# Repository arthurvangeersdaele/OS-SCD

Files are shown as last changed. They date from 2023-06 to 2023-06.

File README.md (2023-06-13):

# The open-source Sequential Compression Device

## Description
The enhancement of an OS Sequential Compression Device (SCD), which combines software and hardware components, to create a suitable hospital device involves a meticulous and iterative process. The objective is to optimize its functionality, usability, and effectiveness, ensuring it meets the specific needs of healthcare professionals and patients alike.

This project has been initied by Schara et al. from Rice University, Huston, and was taken up for a master thesis at UCLouvain by Arthur Van Geersdaele and Thalie Sarafidis. 

## Structure of the .git
A directory has been created for every aspect of the prototype:
- The eletronic design
- The Arduino SCT Software
- The pneumatic band conception
- The risk management (empty at the time this txt file is written)

Don't hesitate to create a new branch for every new iteration of the prototype.

## Support
Arthur Van Geersdaele permanent email: arthurvg@gmail.com

## Acknowledgment
First and foremost, we would like to thank our supervisors, David Bol and Benoît Herman,
for their guidance and support during this academic year. Without their assistance and
suggestions this work would not have been the same. Thank you for all the feed-backs,
your ideas and critiques always helped us to progress.

This thesis could not have existed without the financing by the donations made during
a fundraiser launched by the Louvain Foundation in the first months of the Covid-19
pandemic for the development and distribution of open-source medical devices. We want
to thank the Louvain Fondation and its generous donors. Their donations allowed us to
work on a exciting project with meaning in our eyes. We hope they will be proud of the
work we accomplished.

Any opinions, findings, and conclusions or recommendations expressed in this material are those of the author(s) and do not necessarily reflect the views of the Louvain Fundation.

## License
This project is published under a Creative Commons CC-BY licence by Mark Schara, Mingde Zeng, Jumet and Daniel J. Preston in 2022.

## Overview

<img src="https://lh3.googleusercontent.com/uw4Hd-o32ru7BUOAbB3s1_LTyGWp65Da7H4i2JahnDTs6Ar5mRC0plo9FD7Agp0bvpjEJgBAzZyAgz1ODGIi2wvJs8SYI_CQhsvGnffs6thqfykDg9P1XCusFHrppcjr6rP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" alt="Image of the OS-SCD device interface" width="400"/>

<img src="https://lh3.googleusercontent.com/Dr_NfxmwPY0K1YTv_ehdX9OtSePjZ78id5i1sB04MkSCgEVkiPq_8iiFihfI5J00OjZHkZ0deeg7UaLteDr7LWMCece_ab0Vw5Il7_U0E2uyAFjOePnH3NXgfk2ZkVE7Rpe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" alt="Image of the 3 bands wrapped around the user leg" width="400"/>

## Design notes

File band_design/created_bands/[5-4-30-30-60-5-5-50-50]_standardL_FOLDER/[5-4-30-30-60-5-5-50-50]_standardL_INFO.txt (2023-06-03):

WARNING: SVG has to be converted to paths before being converted to RXF for laser-cutting.
         For better cutting, you can combine the curves using the cutting program.
Tips: The ID of the band is structured as follow 
      [n - ID - l - g - L - ll - gg - Gplus - Gminus]_tag
=========================================================================================

Design specifications
- Reference ID: [5-4-30-30-60-5-5-50-50]_standardL
- Input diameter: 4mm
- Number of pouches: 5
- Dimensions of a pouch: 30x30mm
- Dimensions of the band: 320.0x60mm
- Distance between each pouch: 5mm
- Inner tube width: 5mm
- Additionnal length at the beginning of the pouch-chain (air input to the left): 50mm
- Additionnal length at the end of the pouch-chain: 50mm
- Elbow dimensions: 20x50mm
Others
- TPU Textile dimensions needed for the 2 heat_sealable_layers: 320.0x125mm
- Baking paper dimensions needed for the intermediate_layer: 190x72.5mm
- Nyamara Volume of the band: 31746.77420681033mm3
- Nyamara Volume of the band considering interconnections: 31864.35485202074mm3

NB: The id-box dimensions needed for laser-cutting are written at the end of the filenames.
NB2: Depending on the material used, it can be a retractation of the fabric during the laser-cutting.
     Take that in account while setting your parameters.

Additionnal information on the fabrication process, handwritten
- Material: One-sided TPU coated Textile (70d)
- Fusion process parameters: T=200Celsius, t=30s (set to 200C, 30s default for TPU)

Other notes, remarks..., about [5-4-30-30-60-5-5-50-50]_standardL
***************************************************************************************

***************************************************************************************

 Info file automatically generated at date : 23/04/27 - time : 16h03min40s  using IPCdevice_designer_v2.py

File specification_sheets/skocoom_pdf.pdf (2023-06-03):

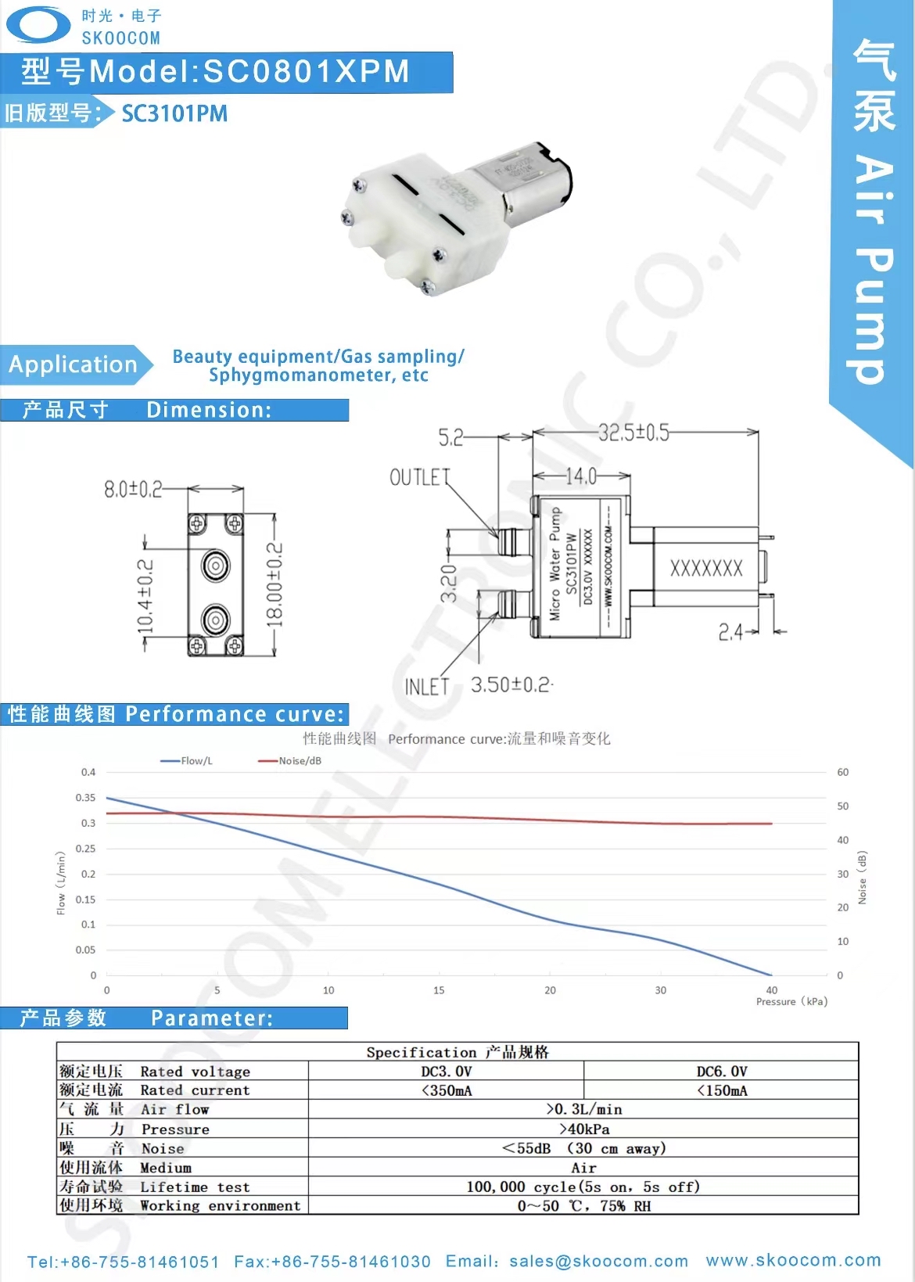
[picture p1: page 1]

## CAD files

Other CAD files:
band_design/created_bands/[5-4-30-30-60-5-5-50-50]_standardL_FOLDER/[5-4-30-30-60-5-5-50-50]_standardL_intermediate_layer(190x72.5mm).dxf
band_design/created_bands/[5-4-30-30-60-5-5-50-50]_standardL_FOLDER/[5-4-30-30-60-5-5-50-50]_standardL_global_render.dxf

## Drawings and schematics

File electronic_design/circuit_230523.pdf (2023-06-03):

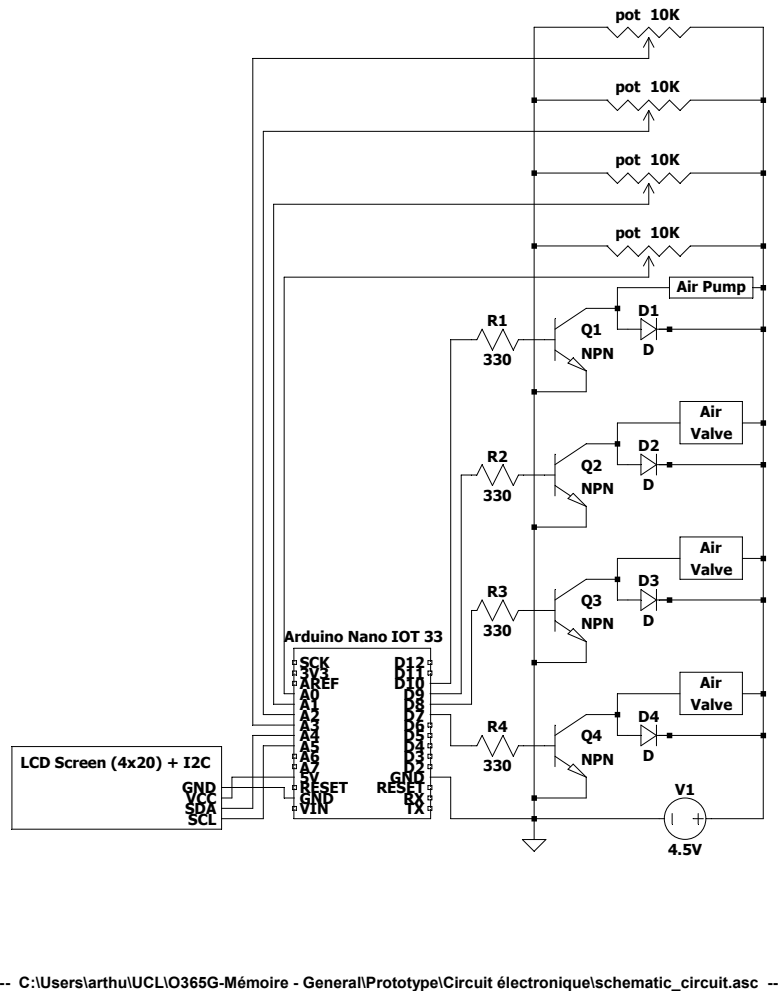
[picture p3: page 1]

Arduino Nano IOT 33
SCK 3V3 AREF A0A1A2A3A4A5A6A75VRESET GND VIN

GND VCC SDA SCL

--- C:\Users\arthu\UCL\O365G-Mémoire - General\Prototype\Circuit électronique\schematic_circuit.asc ---

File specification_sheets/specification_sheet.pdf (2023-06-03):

OS SCD prototype – Overview sheet of the components | may the 30th 2023
p. 1 / 5

## Components - precise description

Drive links may be deprecated or not up-to-date, please refer to the Forge
GitLab linked to this project

The susmentionned GitLab contains every details of the project.

All the specifications sheets we found are stored here https://drive.google.com/drive/folders/1-vRpSUxZW-rc5TYF7eE5loehlPPyNJy3?usp=sharing

Here are some useful links to find electromechanical components :
- https://www.digikey.be/fr/
- RS | Distributeur de composants électroniques et solutions industrielles (rs-online.com)
- https://www.mouser.fr/

The following elements are enhanced descriptions of the components used to build the OS-SCD prototype. With added mechanical and electronical specifications.

Microcontroller
Complete name | Arduino Nano IOT 33with headers (SKU: ABX00032)
Dimensions | 48mm x 18mm
Weight | 5 grams
Operating voltage | 3.3V
Connections | Two 15-pin connectors (one on each side)
Comment | The integrated DC-DC power supply allows you to power the board up to 21V while maintaining high efficiency and providing a significant amount of current to external devices without overheating. 1 piece for 1 device.
Where to buy it | https://store.arduino.cc/products/arduino-nano-33-iot-with-headers
Price | 23.40€/pc.

Battery (from the initial prototype, not implemented in the device yet)
Complete name | Galaxy 2S (7.4V) 120 mAh Lipoly Battery Pack
Dimension s | 19 x 25 x 15.5mm
Weight | 11 grams
Tension de sortie | 7.4V
Connexion s | Mating connector : JST

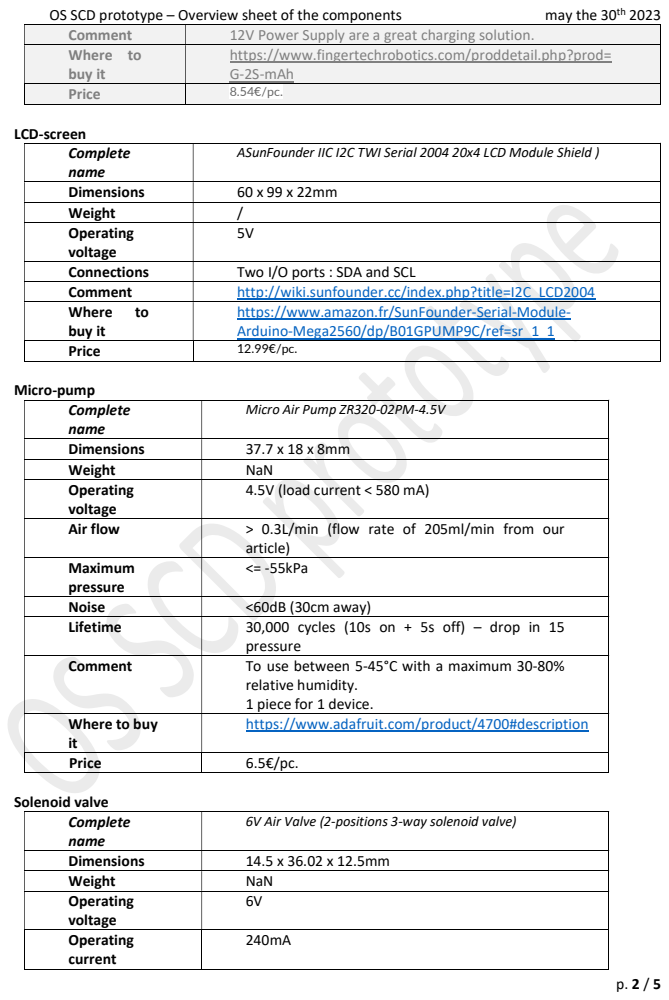
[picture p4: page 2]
LCD-screen; Micro-pump; Solenoid valve

Comment | 12V Power Supply are a great charging solution.
Where to buy it | https://www.fingertechrobotics.com/proddetail.php?prod=G-2S-mAh

Price | 8.54€/pc.

Complete name | ASunFounder IIC I2C TWI Serial 2004 20x4 LCD Module Shield )

Dimensions | 60 x 99 x 22mm
Weight | /
Operating voltage | 5V

Connections | Two I/O ports : SDA and SCL
Comment | http://wiki.sunfounder.cc/index.php?title=I2C_LCD2004
Where to buy it | https://www.amazon.fr/SunFounder-Serial-Module-Arduino-Mega2560/dp/B01GPUMP9C/ref=sr_1_1

Price | 12.99€/pc.

Complete name | Micro Air Pump ZR320-02PM-4.5V

Dimensions | 37.7 x 18 x 8mm
Weight | NaN
Operating voltage | 4.5V (load current < 580 mA)

Air flow | > 0.3L/min (flow rate of 205ml/min from our article)

Maximum pressure | <= -55kPa

Noise | <60dB (30cm away)
Lifetime | 30,000 cycles (10s on + 5s off) – drop in 15 pressure

Comment | To use between 5-45°C with a maximum 30-80% relative humidity. 1 piece for 1 device.

Where to buy it | https://www.adafruit.com/product/4700#description

Price | 6.5€/pc.

Complete name | 6V Air Valve (2-positions 3-way solenoid valve)

Dimensions | 14.5 x 36.02 x 12.5mm
Operating voltage | 6V

Operating current | 240mA

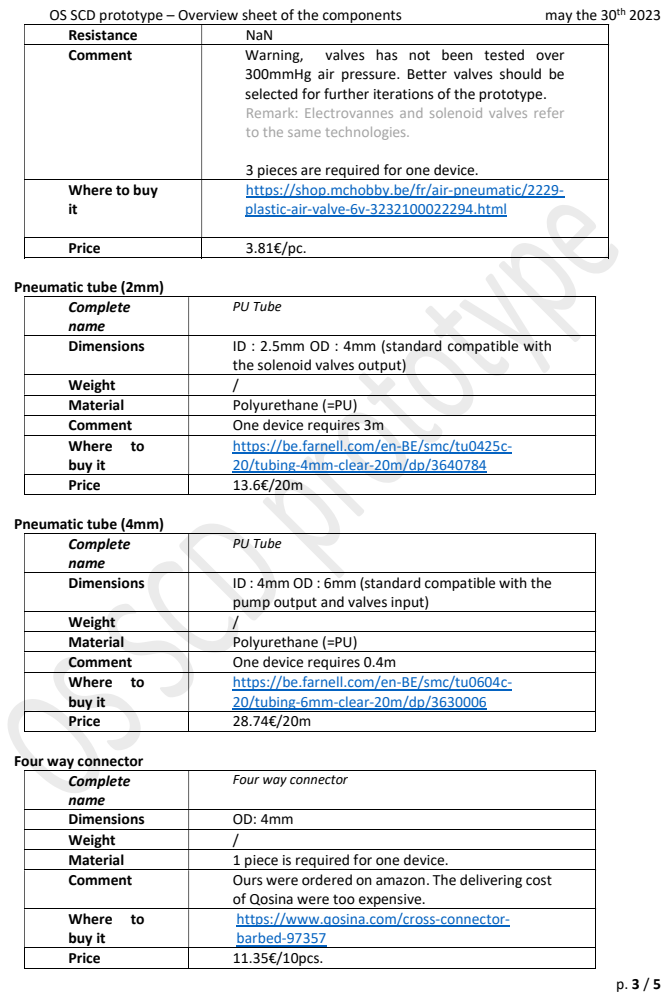
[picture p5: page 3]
Pneumatic tube (2mm); Pneumatic tube (4mm)

Resistance | NaN
Comment | Warning, valves has not been tested over 300mmHg air pressure. Better valves should be selected for further iterations of the prototype. Remark: Electrovannes and solenoid valves refer to the same technologies. 3 pieces are required for one device.

Where to buy it | https://shop.mchobby.be/fr/air-pneumatic/2229-plastic-air-valve-6v-3232100022294.html

Price | 3.81€/pc.

Complete name | PU Tube

Dimensions | ID : 2.5mm OD : 4mm (standard compatible with the solenoid valves output)

Weight | /
Material | Polyurethane (=PU)
Comment | One device requires 3m
Where to buy it | https://be.farnell.com/en-BE/smc/tu0425c-20/tubing-4mm-clear-20m/dp/3640784

Price | 13.6€/20m

Dimensions | ID : 4mm OD : 6mm (standard compatible with the pump output and valves input)

Comment | One device requires 0.4m
Where to buy it | https://be.farnell.com/en-BE/smc/tu0604c-20/tubing-6mm-clear-20m/dp/3630006

Price | 28.74€/20m

Four way connector

Complete name | Four way connector

Dimensions | OD: 4mm
Material | 1 piece is required for one device.
Comment | Ours were ordered on amazon. The delivering cost of Qosina were too expensive.

Where to buy it | https://www.qosina.com/cross-connector-barbed-97357

Price | 11.35€/10pcs.

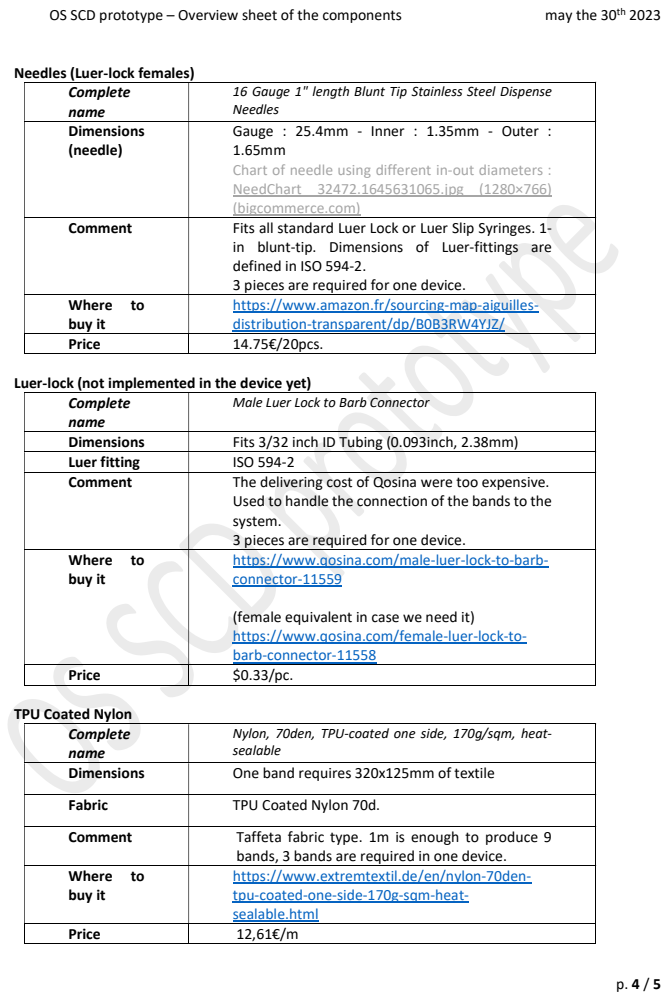
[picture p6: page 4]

Needles (Luer-lock females)

Complete name | 16 Gauge 1" length Blunt Tip Stainless Steel Dispense Needles

Dimensions (needle) | Gauge : 25.4mm - Inner : 1.35mm - Outer : 1.65mm Chart of needle using different in-out diameters : NeedChart__32472.1645631065.jpg (1280×766) (bigcommerce.com)
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

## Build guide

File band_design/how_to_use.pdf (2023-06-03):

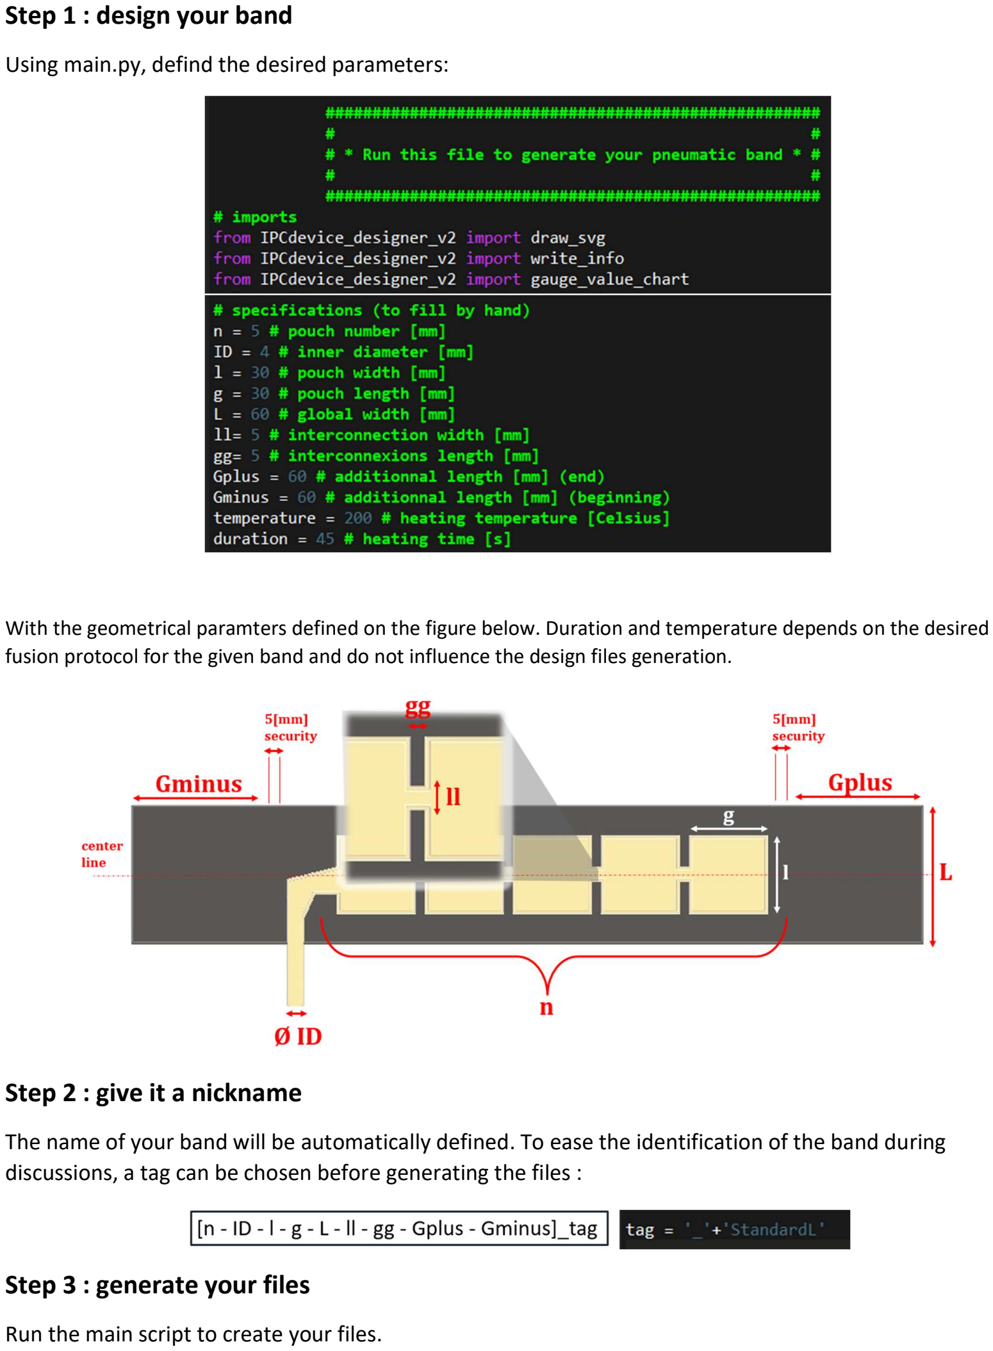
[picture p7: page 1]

Step 1 : design your band

Using main.py, defind the desired parameters:

With the geometrical paramters defined on the figure below. Duration and temperature depends on the desired fusion protocol for the given band and do not influence the design files generation.

Step 2 : give it a nickname

The name of your band will be automatically defined. To ease the identification of the band during discussions, a tag can be chosen before generating the files :

Step 3 : generate your files

Run the main script to create your files.

Step 4 : find your files

After the run, a folder with the name of your band +”_FOLDER” is automatically created in the same repertory as the main.py script.

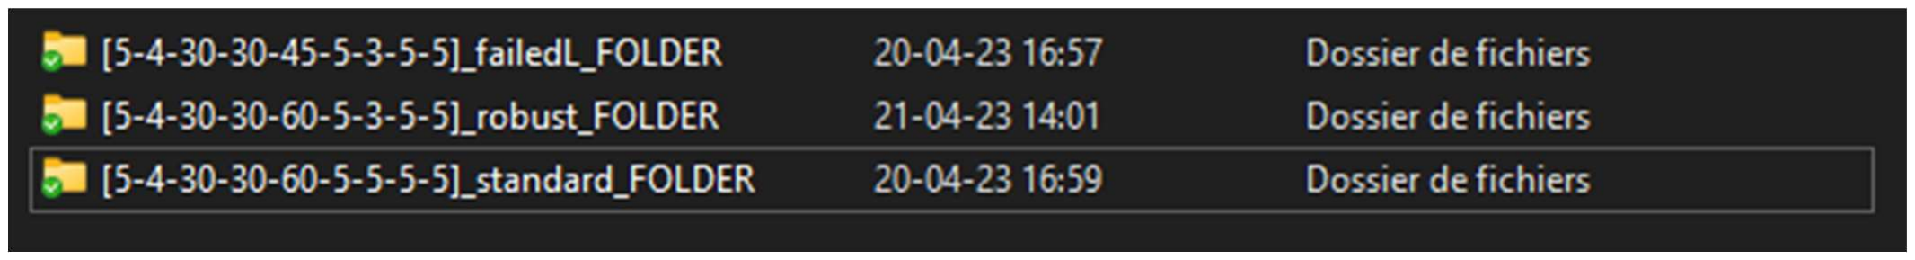
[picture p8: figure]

In the folder, all the needed files are labeled by the name of the band in case they need to be exported out of their initial folder.

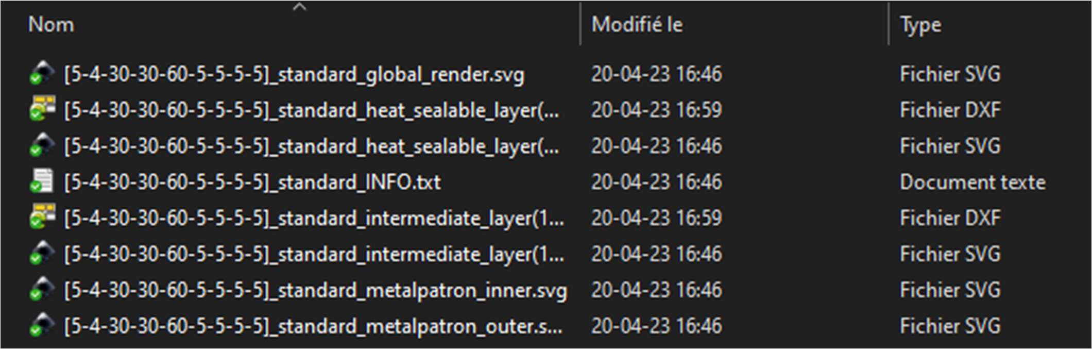
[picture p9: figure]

Among the different files, you will find :
A global render of the band
To verify that the design is correct at first sight. The file is of .svg format.

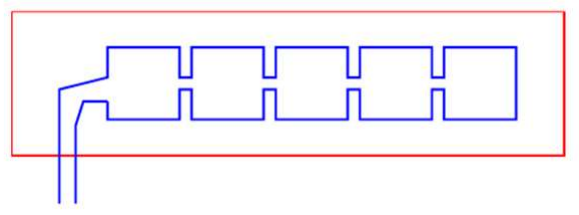
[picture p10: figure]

The distinct cutting files for the heat-sealable layers and the intermediate layer
WARNING: You will need to convert the .svg files to .RXF in order to use them with a laser-cutter.

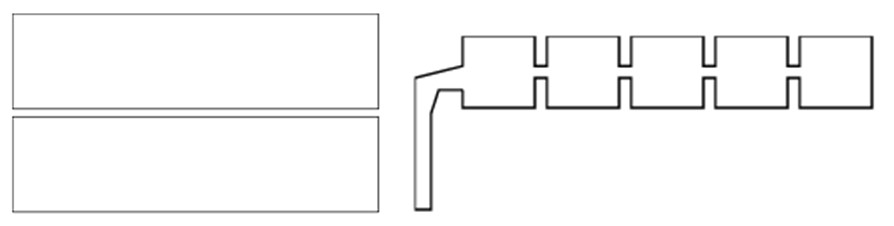
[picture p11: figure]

A first design of a metal-stamp: metal_patron files
They were never tested, but they aim to create a metal stamp to remove the ned of a non-stick layer inside the band.

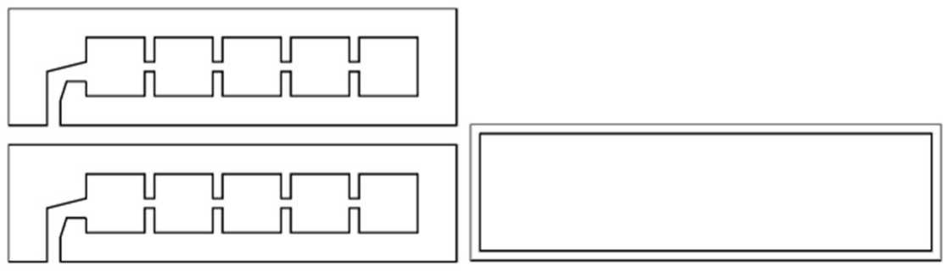
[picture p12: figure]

An info file that resume all the information about the band
The INFO.txt file is the key of the band identification system. It contains everything that is needed to accelerate the fabrication process and to use the band for testing.

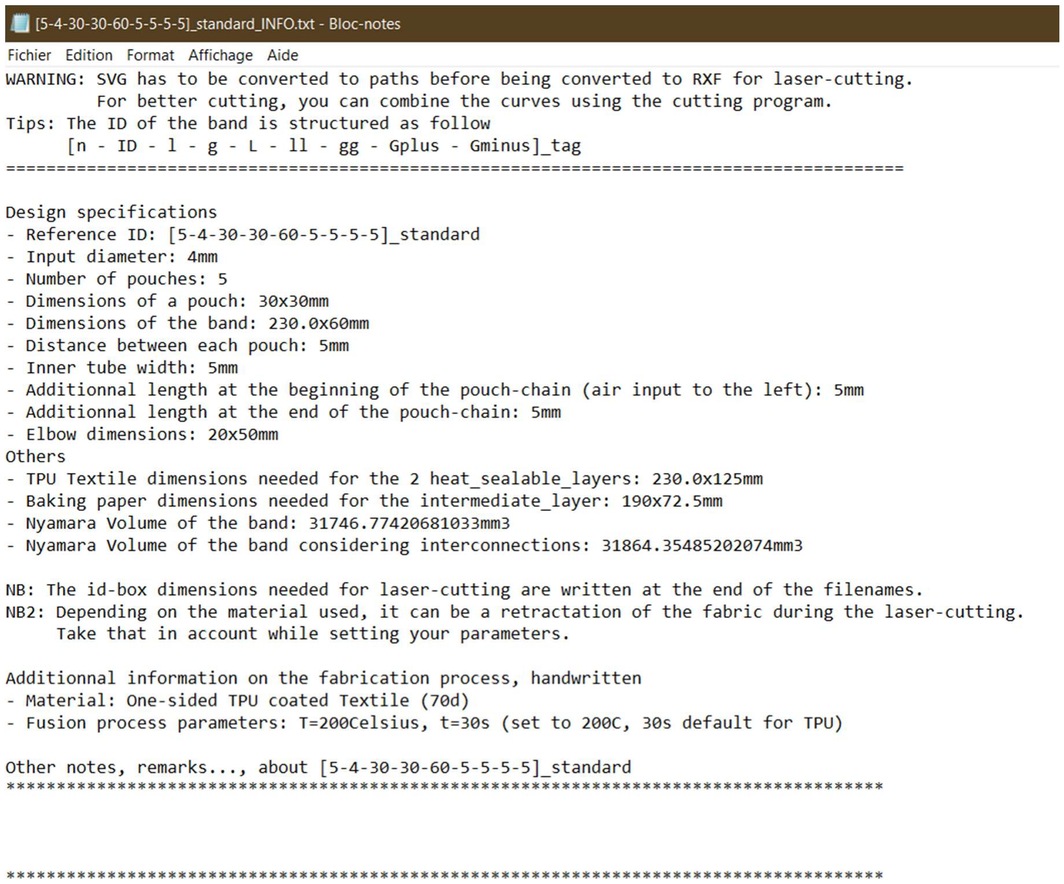
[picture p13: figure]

This file contains :
- A detailed listing of the band design and fusion
- The pre-cutting dimensions needed for the materials to be put in the laser-cutter, ensuring a 5mm security and therefore minimizing material and time loss.
- Estimation of the band volume for a 45 tangential angle using the pouch model of Niiyama et al.
- Other information such as the fusion protocol wanted that can be customized in the code before generation.

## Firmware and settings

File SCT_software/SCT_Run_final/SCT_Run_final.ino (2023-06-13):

#include <LiquidCrystal_I2C.h>
#include <Wire.h>

// #######################  _  _  ____  ____  ____      ____  __   __ _  ____  #######################
// ####################### / )( \/ ___)(  __)(  _ \ ___(__  )/  \ (  ( \(  __) #######################
// ####################### ) \/ (\___ \ ) _)  )   /(___)/ _/(  O )/    / ) _)  #######################
// ####################### \____/(____/(____)(__\_)    (____)\__/ \_)__)(____) #######################

// Arduino connexion pins
// - for pump
int Pump1pin = 10; 
// - for valves (from distal band to proximal)
int valvesPins[] = {9, 8, 7};
// - for potentiometers (ID - impulse duration control, DC - duty cycles control)
int PotIDpin = A0; 
int PotDCPins[] = {A1, A2, A3};

// Specifications 
const int n_bands  = sizeof(valvesPins) / sizeof(int);

// Therapy parameters
unsigned long impulse_duration; // [ms] may be overrided by potentiometer
float duty_cycles[n_bands]; // [%] ~ of a potentiometer and a selector (allows to regulate the inner-pressure)
float impulse_repartition[] = {33.33, 33.33, 33.33}; // [%] (hardcoded: size = n_bands, sum = 100) 
int period = 100; // [ms] (of the duty cycle)
int end_waiting_time = 5000; // [ms]


// #######################  ____   __     __ _   __  ____    ____  ____  __  ____  ####################### 
// ####################### (    \ /  \   (  ( \ /  \(_  _)  (  __)(    \(  )(_  _) ####################### 
// #######################  ) D ((  O )  /    /(  O ) )(     ) _)  ) D ( )(   )(   ####################### 
// ####################### (____/ \__/   \_)__) \__/ (__)   (____)(____/(__) (__)  ####################### 

// Using potentiometers (override precedent parameters if true)
bool impulse_duration_pot = true;
bool duty_cycle_pot = true;

// Time management
unsigned long start_time = 300000; // you got 5 minutes to set up the parameters to the desired values before the SCT starts
unsigned long current_time;
unsigned long condition;
unsigned long remaining;
int counter = 1;

// Screen management
LiquidCrystal_I2C lcd(0x27, 2, 1, 0, 4, 5, 6, 7, 3, POSITIVE);  
char buffer[10];

// Conversion management for potentiometers
int readValue1;
int readValue2;
float writeReadConversion=255./1023.;
unsigned long writeValue1;
unsigned long writeValue2;

// Useful functions for therapy
void contraction(int pin, float onTime, float offTime){
  digitalWrite(pin, HIGH);
  delay(onTime);
  digitalWrite(pin, LOW);
  delay(offTime);
};

void sequence(int i, int pin, float onTime, float offTime){
  digitalWrite(pin, HIGH);
  while (millis() -  start_time - round((float) (impulse_duration + end_waiting_time)*(counter-1)) < impulse_repartition[i] * impulse_duration /100) {
  //while (millis() -  start_time - (impulse_duration + end_waiting_time)*(counter-1) < round((float) impulse_repartition[i] * impulse_duration /100)) {
    contraction(pin, onTime, offTime);
  }
  digitalWrite(pin, LOW);
};

// Useful structural function 
void cumulative(float* tmp, int n_bands) {
  for (int i = 1; i < n_bands; i++) {
    tmp[i] = tmp[i] + tmp[i-1];
  }
}

// TODO : LCD function to light the code

void setup() {
  // Debug and feedbacks
  Serial.begin(9600);
  lcd.begin(20, 4);

  // PinModes
  pinMode(Pump1pin, OUTPUT);
  pinMode(PotIDpin, INPUT);
  for (int i = 0; i < n_bands; i++) {
    pinMode(valvesPins[i], OUTPUT);
    pinMode(PotDCPins[i], INPUT);
  }

  // Data conversion
  cumulative(impulse_repartition, n_bands);
    
  if (!impulse_duration_pot) {
    impulse_duration = 15000;
  }
  if (!duty_cycle_pot) {
    for (int i = 0; i < n_bands; i++) {
      duty_cycles[i] = 100.0;
    }
  }
  // For Start confirmation
  pinMode(LED_BUILTIN, OUTPUT);
  digitalWrite(LED_BUILTIN, HIGH);delay(1000);digitalWrite(LED_BUILTIN, LOW);
  delay(1000);
  digitalWrite(LED_BUILTIN, HIGH);delay(1000);digitalWrite(LED_BUILTIN, LOW);
  delay(1000);
  digitalWrite(LED_BUILTIN, HIGH);delay(1000);digitalWrite(LED_BUILTIN, LOW);

  // Setting phase
  lcd.clear();
  // Display setting title
  lcd.setCursor(0, 0);
  lcd.print("[SCT SETTINGS]");     
  // - display impulse duration label
  lcd.setCursor(0, 1);
  lcd.print("ID: "); 
  lcd.setCursor(17, 1);
  lcd.print("[s]"); 
  // - display duty cycles label
  lcd.setCursor(0, 2);
  lcd.print("DC: "); 
  lcd.setCursor(17, 2);
  lcd.print("[%]");
  // Starting (setting phase)
  current_time = millis();
  while(current_time < start_time){  
    current_time = millis();
    // - display impulse duration
    lcd.setCursor(4, 1);
    dtostrf(impulse_duration/1000, 2, 0, buffer);
    lcd.print(buffer);
    // - display duty cycles
    for(int i = 0; i < n_bands; i++){
      lcd.setCursor(3+i*4, 2);
      dtostrf(duty_cycles[i], 3, 0, buffer);
      lcd.print(buffer);
      if(i != n_bands-1){
        lcd.print("/"); 
      }
    }
  // Potentiometers for period
  if(impulse_duration_pot){
    readValue1=analogRead(PotIDpin);
    writeValue1 = map(readValue1, 0.0, 1023.0, 6000, 91000) - 500;
    impulse_duration = writeValue1;
  }
  // Potentiometers for duty_cycle
  if(duty_cycle_pot){
    for(int i = 0; i < n_bands; i++){
        readValue2 = analogRead(PotDCPins[i]);
        writeValue2 =  map(readValue2, 0.0, 1023.0, 900, 1001);
        duty_cycles[i] = writeValue2/10;
      }
    }
    // - display remaining time before SCT
    lcd.setCursor(0, 3);
    lcd.print("time left: "); 
    lcd.setCursor(10, 3);
    remaining = start_time - current_time;
    dtostrf(remaining/1000.0, 3, 0, buffer);
    lcd.print(buffer); 
    lcd.setCursor(17, 3);
    lcd.print("[s]"); 
    delay(500);
  }
  
  // Display SCT running title
  lcd.setCursor(0, 0);
  lcd.print("[SCT RUNNING] "); 
  // Display total SCT duration
  lcd.setCursor(0, 3);
  lcd.print("time:          "); 
  lcd.setCursor(15, 3);
  lcd.print("[min]");
  // Handling time
  start_time = millis();
  // Pump start
  digitalWrite(Pump1pin, HIGH);
}

void loop() {
  // Display total SCT duration
  lcd.setCursor(5, 3);
  current_time = millis();
  remaining = current_time - start_time;
  dtostrf(remaining/60000.0, 3, 0, buffer);
  lcd.print(buffer); 
  // Straps inflation
  for (int i = 0; i < n_bands; i++) {
    // Duty Cycle
    float onTime = (duty_cycles[i] / 100.0) * period;
    float offTime = period - onTime;
    Serial.println(duty_cycles[i]);
    // Impulse sequence
    sequence(i, valvesPins[i], onTime, offTime);
  }
  delay(end_waiting_time);
  counter = counter+1;
}

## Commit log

2023-06-03 Added folders to the main branch
    [[5-4-30-30-60-5-5-50-50]_standardL_global_render.dxf, [5-4-30-30-60-5-5-50-50]_standardL_intermediate_layer(190x72.5mm).dxf]
2023-06-12 Adding the device electronic box (for lasercutters)
2023-06-13 Adding prototype pictures to the READ_ME.md
